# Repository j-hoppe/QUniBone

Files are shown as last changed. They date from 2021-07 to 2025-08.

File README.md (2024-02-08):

# QUniBone
This is the software for both
Linux-to-UNIBUS bridge "UniBone"
and
Linux-to-QBUS bridge "QBone"

"UniBone" connects a BeagleBone Black micro Linux system to ancient DEC UNIBUS,
"QBone" does the same for DEC QBUS.

UniBone/QBone can keep old PDP-11s running, by emulating devices and aiding in repair.

As UNIBUS and QBUS are quite similar, only one software project compiles for both devices.

In-source differentiation is done via "#define UNIBUS" or "#define QBUS".
Source files special to only one bus are marked with suffix "_u" respective "_q".

See project pages at retrocmp.com [for UniBone](http://retrocmp.com/projects/unibone/) and [for QBone](http://retrocmp.com/projects/qbone/)

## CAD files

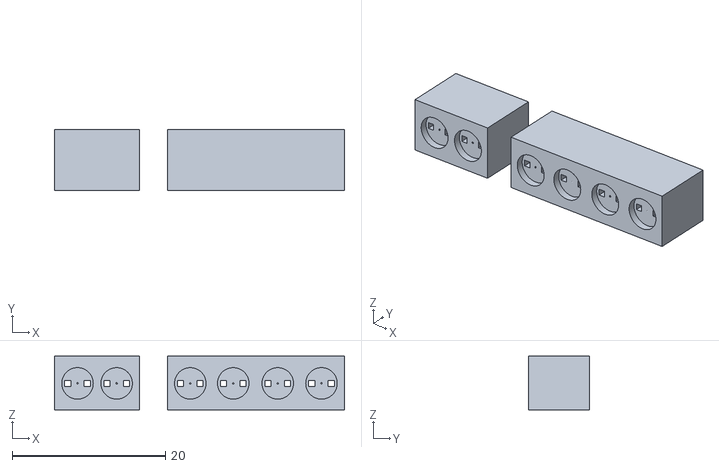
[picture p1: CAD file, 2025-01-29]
01.01_pcb/3d/UniBone2023Leds3mm.stl
37.8 x 8.00 x 7.00

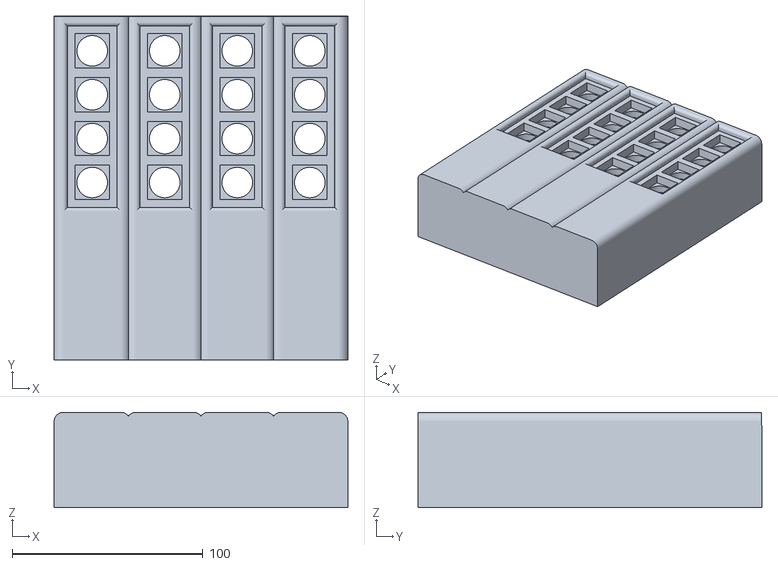
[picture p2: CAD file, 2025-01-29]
01.02_panel/building/rl02panel.stl
154.0 x 180.2 x 50.0

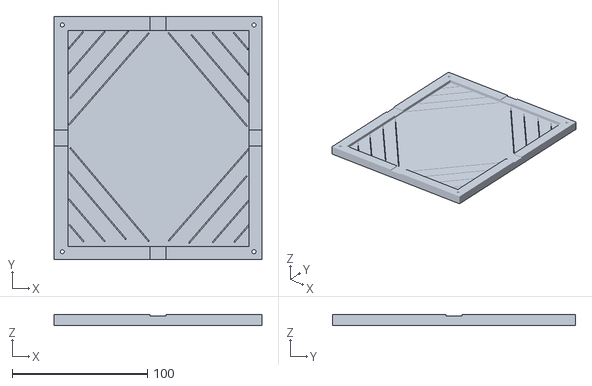
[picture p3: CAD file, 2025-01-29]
01.02_panel/building/rl02panel-bottom.stl
154.0 x 180.0 x 8.00

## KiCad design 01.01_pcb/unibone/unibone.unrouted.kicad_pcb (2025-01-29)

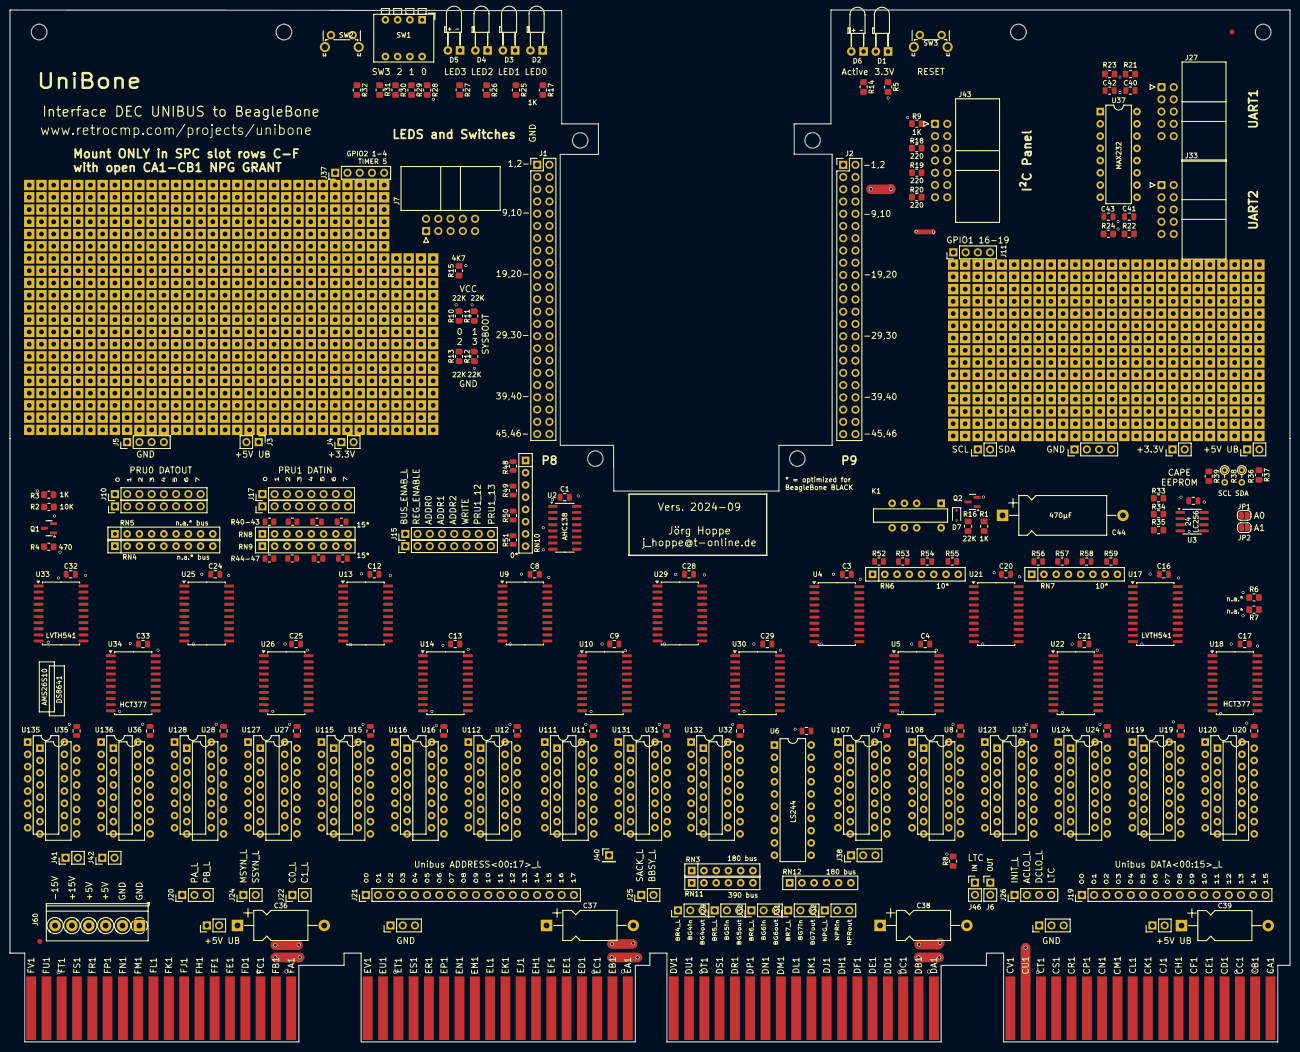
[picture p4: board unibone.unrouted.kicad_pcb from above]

Board: 4 copper layers, 265.6 x 214.1 mm, 1317 parts (0 on the bottom side), 321 nets.

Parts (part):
C1, C2, C3, C4, C5, C6, C7, C8, C9, C10, C11, C12, C13, C14, C15, C16, C17, C18, C19, C20, C21, C22, C23, C24, C25, C26, C27, C28, C29, C30, C31, C32, C33, C34, C35: 100nF; C_0805_2012Metric
C36, C37, C38, C39: 6.3uF; CP_Axial_L11.0mm_D6.0mm_P18.00mm_Horizontal
C40, C41, C42, C43: 1uF; C_0805_2012Metric
C44: 470uF; CP_Axial_L18.0mm_D8.0mm_P25.00mm_Horizontal
D1: PWR; LED_D3.0mm_Horizontal_O3.81mm_Z2.0mm
D2: LED0; LED_D3.0mm_Horizontal_O3.81mm_Z2.0mm
D3: LED1; LED_D3.0mm_Horizontal_O3.81mm_Z2.0mm
D4: LED2; LED_D3.0mm_Horizontal_O3.81mm_Z2.0mm
D5: LED3; LED_D3.0mm_Horizontal_O3.81mm_Z2.0mm
D6: ONBUS; LED_D3.0mm_Horizontal_O3.81mm_Z2.0mm
D7: 1N4148WS; D_SOD-323
DECHANDLE1, DECHANDLE2: DEC Handle; DEC-Handle
F1, F2: Fiducial
H1, H2, H7, H8: NPTH; HOLE-3MM
HOLE1, HOLE2, HOLE3, HOLE4: MountingHole_3.2mm_M3
J1: BBB-P8; PinHeader_2x23_P2.54mm_Vertical
J2: BBB-P9; PinHeader_2x23_P2.54mm_Vertical
J3, J35: +5V UB; PinHeader_1x02_P2.54mm_Vertical
J4, J34: +3.3V; PinHeader_1x02_P2.54mm_Vertical
J5, J36: GND; PinHeader_1x04_P2.54mm_Vertical
J6: LTC_OUT; PinHeader_1x02_P2.54mm_Vertical
J7: Panel; IDC-Header_2x05_P2.54mm_Horizontal
J10: REG_DATA_FROM_PRU0; PinHeader_1x08_P2.54mm_Vertical
J11: GPIO1_16-19; PinHeader_1x04_P2.54mm_Vertical
J13, J14: GND; PinHeader_1x03_P2.54mm_Vertical
J15: PRU_CONTROL; PinHeader_1x08_P2.54mm_Vertical
J16: CONN-DEC-QUAD-CDEF; dec-conn-quad-ht-pins-only_CDEF
J17: REG_DATA_TO_PRU1; PinHeader_1x08_P2.54mm_Vertical
J19: UB_DATA; PinHeader_1x16_P2.54mm_Vertical
J20: UB_INTR_PAB; PinHeader_1x03_P2.54mm_Vertical
J21: UB_ADDR; PinHeader_1x18_P2.54mm_Vertical
J22: UB_C01; PinHeader_1x02_P2.54mm_Vertical
J23, J56, J57: GND; PinHeader_1x08_P2.54mm_Vertical
J24: UB_MSYN; PinHeader_1x02_P2.54mm_Vertical
J25: UB_SKBY; PinHeader_1x02_P2.54mm_Vertical
J26: UB_MISC; PinHeader_1x04_P2.54mm_Vertical
J27: UART1_RS232_Schneid-Klemm_2x5; IDC-Header_2x05_P2.54mm_Horizontal
J28: UB_BRG4; PinHeader_1x03_P2.54mm_Vertical
J29: UB_BRG5; PinHeader_1x03_P2.54mm_Vertical
J30: UB_BRG6; PinHeader_1x03_P2.54mm_Vertical
J31: UB_BRG7; PinHeader_1x03_P2.54mm_Vertical
J32: UB_NPRG; PinHeader_1x03_P2.54mm_Vertical
J33: UART2_RS232_Schneid-Klemm_2x5; IDC-Header_2x05_P2.54mm_Horizontal
J37: GPIO2_1-5; PinHeader_1x05_P2.54mm_Vertical
J38: -; PinHeader_1x03_P2.54mm_Vertical
J40: Conn_01x01; PinHeader_1x01_P2.54mm_Vertical
J41, J42, J61, J62: Conn_01x02_Male; PinHeader_1x02_P2.54mm_Vertical
J43: Panel_I2C; IDC-Header_2x07_P2.54mm_Horizontal
J46: LTC_IN; PinHeader_1x02_P2.54mm_Vertical
J59: I2C2; PinHeader_1x02_P2.54mm_Vertical
J60: Reichelt AKL 059-6; TerminalBlock_Phoenix_PT-1,5-6-3.5-H_1x06_P3.50mm_Horizontal
JP1: A0; SolderJumper-2_P1.3mm_Open_RoundedPad1.0x1.5mm
JP2: A1; SolderJumper-2_P1.3mm_Open_RoundedPad1.0x1.5mm
K1: HFD3; HFD3-relay
Q1, Q2: MMBT3904; SOT-23
R1, R3, R8, R9, R17, R25, R26, R27, R28, R29, R30, R31, R32: 1K; R_0805_2012Metric_Pad1.20x1.40mm_HandSolder
R2, R33, R34, R35, R37, R39: 10K; R_0805_2012Metric_Pad1.20x1.40mm_HandSolder
R4, R5, R14: 470; R_0805_2012Metric_Pad1.20x1.40mm_HandSolder
R6, R7: none; R_0805_2012Metric_Pad1.20x1.40mm_HandSolder
R10, R11, R12, R13, R16: 22K; R_0805_2012Metric_Pad1.20x1.40mm_HandSolder
R15: 4K7; R_0805_2012Metric_Pad1.20x1.40mm_HandSolder
R18, R19, R20: 220; R_0805_2012Metric_Pad1.20x1.40mm_HandSolder
R21, R22: 2K2; R_0805_2012Metric_Pad1.20x1.40mm_HandSolder
R23, R24: 3K3; R_0805_2012Metric_Pad1.20x1.40mm_HandSolder
R36, R38: opt.; R_Axial_DIN0204_L3.6mm_D1.6mm_P2.54mm_Vertical
R40, R41, R42, R43, R44, R45, R46, R47: 15; R_0805_2012Metric
R48, R49, R50, R51: 0; R_0805_2012Metric
R52, R53, R54, R55, R56, R57, R58, R59: 10; R_0805_2012Metric
RN3, RN12: 180; R_Array_SIP6
RN4, RN5: n.a.; R_Array_SIP9
RN6, RN7: 10; R_Array_SIP8
RN8, RN9: 15; R_Array_SIP8
RN10: 0; R_Array_SIP8
RN11: 390; R_Array_SIP6
SW1: SW0-3; SW_DIP_SPSTx04_Piano_CTS_Series194-4MSTN_W7.62mm_P2.54mm
SW2, SW3: BTN; SW_Tactile_SPST_Angled_PTS645Vx58-2LFS
U2: 74AHC138; SOIC-16_3.9x9.9mm_P1.27mm
U3: 24LC256; SOIC-8_3.9x4.9mm_P1.27mm
U4, U9, U13, U17, U21, U25, U29, U33: 74LVTH541_PWR; SOIC-20W_7.5x12.8mm_P1.27mm
U5, U10, U14, U18, U22, U26, U30, U34: 74HCT377; SOIC-20W_7.5x12.8mm_P1.27mm
U6: 74LS244_5V; DIP-20_W7.62mm
U7, U8, U11, U12, U15, U16, U19, U20, U23, U24, U27, U28, U31, U32, U35, U36: DS8641-LR; DIP-16_W7.62mm
U37: MAX232; DIP-16_W7.62mm
U107, U108, U111, U112, U115, U116, U119, U120, U123, U124, U127, U128, U131, U132, U135, U136: AM26S10; DIP-16_W7.62mm
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

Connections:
+3.3V: C1.2, C2.1, C3.2, C8.2, C12.2, C16.2, C20.2, C24.2, C28.2, C32.2, D1.2 (A), D2.2 (A), D3.2 (A), D4.2 (A), D5.2 (A), D6.2 (A), J2.3, J2.4, J4.1, J4.2, J34.1, J34.2, J43.5, JP1.2 (B), JP2.2 (B), R6.1, R10.1, R11.1, R35.1, R36.1, R37.1, R38.1, R39.1, RN5.1 (common), SW1.1, SW1.2, SW1.3, SW1.4, SW2.1, U2.16 (VCC), U3.8 (VCC), U4.20 (VCC), U9.20 (VCC), U13.20 (VCC), U17.20 (VCC), U21.20 (VCC), U25.20 (VCC), U29.20 (VCC), U33.20 (VCC)
+5VA: J2.5, J2.6, K1.5, K1.8, U37.16 (VCC)
/DS8641-ADR07/busdriver3/in1: U10.2 (Q0), U11.14 (in1), U111.13 (4D)
/DS8641-ADR07/busdriver3/in2: U10.5 (Q1), U11.11 (in2), U111.11 (3D)
/DS8641-ADR07/busdriver3/in3: U10.6 (Q2), U11.2 (in3), U111.4 (1D)
/DS8641-ADR07/busdriver3/in4: U10.9 (Q3), U11.5 (in4), U111.5 (2D)
/DS8641-ADR07/busdriver3/out1: U9.2 (A0), U11.13 (out1), U111.14 (4R)
/DS8641-ADR07/busdriver3/out2: U9.3 (A1), U11.10 (out2), U111.10 (3R)
/DS8641-ADR07/busdriver3/out3: U9.4 (A2), U11.3 (out3), U111.3 (1R)
/DS8641-ADR07/busdriver3/out4: U9.5 (A3), U11.6 (out4), U111.6 (2R)
/DS8641-ADR07/busdriver4/in1: U10.12 (Q4), U12.14 (in1), U112.13 (4D)
/DS8641-ADR07/busdriver4/in2: U10.15 (Q5), U12.11 (in2), U112.11 (3D)
/DS8641-ADR07/busdriver4/in3: U10.16 (Q6), U12.2 (in3), U112.4 (1D)
/DS8641-ADR07/busdriver4/in4: U10.19 (Q7), U12.5 (in4), U112.5 (2D)
/DS8641-ADR07/busdriver4/out1: U9.6 (A4), U12.13 (out1), U112.14 (4R)
/DS8641-ADR07/busdriver4/out2: U9.7 (A5), U12.10 (out2), U112.10 (3R)
/DS8641-ADR07/busdriver4/out3: U9.8 (A6), U12.3 (out3), U112.3 (1R)
/DS8641-ADR07/busdriver4/out4: U9.9 (A7), U12.6 (out4), U112.6 (2R)
/DS8641-ADR167+MSYN/busdriver3/in1: U26.2 (Q0), U27.14 (in1), U127.13 (4D)
/DS8641-ADR167+MSYN/busdriver3/in2: U26.5 (Q1), U27.11 (in2), U127.11 (3D)
/DS8641-ADR167+MSYN/busdriver3/in3: U26.6 (Q2), U27.2 (in3), U127.4 (1D)
/DS8641-ADR167+MSYN/busdriver3/in4: U26.9 (Q3), U27.5 (in4), U127.5 (2D)
/DS8641-ADR167+MSYN/busdriver3/out1: U25.2 (A0), U27.13 (out1), U127.14 (4R)
/DS8641-ADR167+MSYN/busdriver3/out2: U25.3 (A1), U27.10 (out2), U127.10 (3R)
/DS8641-ADR167+MSYN/busdriver3/out3: U25.4 (A2), U27.3 (out3), U127.3 (1R)
/DS8641-ADR167+MSYN/busdriver3/out4: U25.5 (A3), U27.6 (out4), U127.6 (2R)
/DS8641-ADR167+MSYN/busdriver4/bus3: J41.1, U28.1 (bus3), U128.2 (1B)
/DS8641-ADR167+MSYN/busdriver4/bus4: J41.2, U28.4 (bus4), U128.7 (2B)
/DS8641-ADR167+MSYN/busdriver4/in1: U26.12 (Q4), U28.14 (in1), U128.13 (4D)
/DS8641-ADR167+MSYN/busdriver4/in2: U26.15 (Q5), U28.11 (in2), U128.11 (3D)
/DS8641-ADR167+MSYN/busdriver4/in3: U26.16 (Q6), U28.2 (in3), U128.4 (1D)
/DS8641-ADR167+MSYN/busdriver4/in4: U26.19 (Q7), U28.5 (in4), U128.5 (2D)
/DS8641-ADR167+MSYN/busdriver4/out1: U25.6 (A4), U28.13 (out1), U128.14 (4R)
/DS8641-ADR167+MSYN/busdriver4/out2: U25.7 (A5), U28.10 (out2), U128.10 (3R)
/DS8641-ADR167+MSYN/busdriver4/out3: U25.8 (A6), U28.3 (out3), U128.3 (1R)
/DS8641-ADR167+MSYN/busdriver4/out4: U25.9 (A7), U28.6 (out4), U128.6 (2R)
/DS8641-ADR815/busdriver3/in1: U14.2 (Q0), U15.14 (in1), U115.13 (4D)
/DS8641-ADR815/busdriver3/in2: U14.5 (Q1), U15.11 (in2), U115.11 (3D)
/DS8641-ADR815/busdriver3/in3: U14.6 (Q2), U15.2 (in3), U115.4 (1D)
/DS8641-ADR815/busdriver3/in4: U14.9 (Q3), U15.5 (in4), U115.5 (2D)
/DS8641-ADR815/busdriver3/out1: U13.2 (A0), U15.13 (out1), U115.14 (4R)
/DS8641-ADR815/busdriver3/out2: U13.3 (A1), U15.10 (out2), U115.10 (3R)
/DS8641-ADR815/busdriver3/out3: U13.4 (A2), U15.3 (out3), U115.3 (1R)
/DS8641-ADR815/busdriver3/out4: U13.5 (A3), U15.6 (out4), U115.6 (2R)
/DS8641-ADR815/busdriver4/in1: U14.12 (Q4), U16.14 (in1), U116.13 (4D)
/DS8641-ADR815/busdriver4/in2: U14.15 (Q5), U16.11 (in2), U116.11 (3D)
/DS8641-ADR815/busdriver4/in3: U14.16 (Q6), U16.2 (in3), U116.4 (1D)
/DS8641-ADR815/busdriver4/in4: U14.19 (Q7), U16.5 (in4), U116.5 (2D)
/DS8641-ADR815/busdriver4/out1: U13.6 (A4), U16.13 (out1), U116.14 (4R)
/DS8641-ADR815/busdriver4/out2: U13.7 (A5), U16.10 (out2), U116.10 (3R)
/DS8641-ADR815/busdriver4/out3: U13.8 (A6), U16.3 (out3), U116.3 (1R)
/DS8641-ADR815/busdriver4/out4: U13.9 (A7), U16.6 (out4), U116.6 (2R)
/DS8641-ARB/busdriver3/in1: U30.2 (Q0), U31.14 (in1), U131.13 (4D)
/DS8641-ARB/busdriver3/in2: U30.5 (Q1), U31.11 (in2), U131.11 (3D)
/DS8641-ARB/busdriver3/in3: U30.6 (Q2), U31.2 (in3), U131.4 (1D)
/DS8641-ARB/busdriver3/in4: U30.9 (Q3), U31.5 (in4), U131.5 (2D)
/DS8641-ARB/busdriver3/out1: U29.2 (A0), U31.13 (out1), U131.14 (4R)
/DS8641-ARB/busdriver3/out2: U29.3 (A1), U31.10 (out2), U131.10 (3R)
/DS8641-ARB/busdriver3/out3: U29.4 (A2), U31.3 (out3), U131.3 (1R)
/DS8641-ARB/busdriver3/out4: U29.5 (A3), U31.6 (out4), U131.6 (2R)
/DS8641-ARB/busdriver4/bus4: J40.1, U32.4 (bus4), U132.7 (2B)
/DS8641-ARB/busdriver4/in1: U30.12 (Q4), U32.14 (in1), U132.13 (4D)
/DS8641-ARB/busdriver4/in2: U30.15 (Q5), U32.11 (in2), U132.11 (3D)
/DS8641-ARB/busdriver4/in3: U30.16 (Q6), U32.2 (in3), U132.4 (1D)
/DS8641-ARB/busdriver4/in4: U30.19 (Q7), U32.5 (in4), U132.5 (2D)
/DS8641-ARB/busdriver4/out1: U29.6 (A4), U32.13 (out1), U132.14 (4R)
/DS8641-ARB/busdriver4/out2: U29.7 (A5), U32.10 (out2), U132.10 (3R)
/DS8641-ARB/busdriver4/out3: U29.8 (A6), U32.3 (out3), U132.3 (1R)
/DS8641-ARB/busdriver4/out4: U29.9 (A7), U32.6 (out4), U132.6 (2R)
/DS8641-DAT07/busdriver3/in1: U18.2 (Q0), U19.14 (in1), U119.13 (4D)
/DS8641-DAT07/busdriver3/in2: U18.5 (Q1), U19.11 (in2), U119.11 (3D)
/DS8641-DAT07/busdriver3/in3: U18.6 (Q2), U19.2 (in3), U119.4 (1D)
/DS8641-DAT07/busdriver3/in4: U18.9 (Q3), U19.5 (in4), U119.5 (2D)
/DS8641-DAT07/busdriver3/out1: U17.2 (A0), U19.13 (out1), U119.14 (4R)
/DS8641-DAT07/busdriver3/out2: U17.3 (A1), U19.10 (out2), U119.10 (3R)
/DS8641-DAT07/busdriver3/out3: U17.4 (A2), U19.3 (out3), U119.3 (1R)
/DS8641-DAT07/busdriver3/out4: U17.5 (A3), U19.6 (out4), U119.6 (2R)
/DS8641-DAT07/busdriver4/in1: U18.12 (Q4), U20.14 (in1), U120.13 (4D)
/DS8641-DAT07/busdriver4/in2: U18.15 (Q5), U20.11 (in2), U120.11 (3D)
/DS8641-DAT07/busdriver4/in3: U18.16 (Q6), U20.2 (in3), U120.4 (1D)
/DS8641-DAT07/busdriver4/in4: U18.19 (Q7), U20.5 (in4), U120.5 (2D)
/DS8641-DAT07/busdriver4/out1: U17.6 (A4), U20.13 (out1), U120.14 (4R)
/DS8641-DAT07/busdriver4/out2: U17.7 (A5), U20.10 (out2), U120.10 (3R)
/DS8641-DAT07/busdriver4/out3: U17.8 (A6), U20.3 (out3), U120.3 (1R)
/DS8641-DAT07/busdriver4/out4: U17.9 (A7), U20.6 (out4), U120.6 (2R)
/DS8641-DAT815/busdriver3/in1: U22.2 (Q0), U23.14 (in1), U123.13 (4D)
/DS8641-DAT815/busdriver3/in2: U22.5 (Q1), U23.11 (in2), U123.11 (3D)
/DS8641-DAT815/busdriver3/in3: U22.6 (Q2), U23.2 (in3), U123.4 (1D)
/DS8641-DAT815/busdriver3/in4: U22.9 (Q3), U23.5 (in4), U123.5 (2D)
/DS8641-DAT815/busdriver3/out1: U21.2 (A0), U23.13 (out1), U123.14 (4R)
/DS8641-DAT815/busdriver3/out2: U21.3 (A1), U23.10 (out2), U123.10 (3R)
/DS8641-DAT815/busdriver3/out3: U21.4 (A2), U23.3 (out3), U123.3 (1R)
/DS8641-DAT815/busdriver3/out4: U21.5 (A3), U23.6 (out4), U123.6 (2R)
/DS8641-DAT815/busdriver4/in1: U22.12 (Q4), U24.14 (in1), U124.13 (4D)
/DS8641-DAT815/busdriver4/in2: U22.15 (Q5), U24.11 (in2), U124.11 (3D)
/DS8641-DAT815/busdriver4/in3: U22.16 (Q6), U24.2 (in3), U124.4 (1D)
/DS8641-DAT815/busdriver4/in4: U22.19 (Q7), U24.5 (in4), U124.5 (2D)
/DS8641-DAT815/busdriver4/out1: U21.6 (A4), U24.13 (out1), U124.14 (4R)
/DS8641-DAT815/busdriver4/out2: U21.7 (A5), U24.10 (out2), U124.10 (3R)
/DS8641-DAT815/busdriver4/out3: U21.8 (A6), U24.3 (out3), U124.3 (1R)
/DS8641-DAT815/busdriver4/out4: U21.9 (A7), U24.6 (out4), U124.6 (2R)
/DS8641-SSYN+MISC/busdriver3/in1: U34.2 (Q0), U35.14 (in1), U135.13 (4D)
/DS8641-SSYN+MISC/busdriver3/in2: U34.5 (Q1), U35.11 (in2), U135.11 (3D)
/DS8641-SSYN+MISC/busdriver3/in3: U34.6 (Q2), U35.2 (in3), U135.4 (1D)
/DS8641-SSYN+MISC/busdriver3/in4: U34.9 (Q3), U35.5 (in4), U135.5 (2D)
/DS8641-SSYN+MISC/busdriver3/out1: U33.2 (A0), U35.13 (out1), U135.14 (4R)
/DS8641-SSYN+MISC/busdriver3/out2: U33.3 (A1), U35.10 (out2), U135.10 (3R)
/DS8641-SSYN+MISC/busdriver3/out3: U33.4 (A2), U35.3 (out3), U135.3 (1R)
/DS8641-SSYN+MISC/busdriver3/out4: U33.5 (A3), U35.6 (out4), U135.6 (2R)
/DS8641-SSYN+MISC/busdriver4/bus3: J42.1, U36.1 (bus3), U136.2 (1B)
/DS8641-SSYN+MISC/busdriver4/bus4: J42.2, U36.4 (bus4), U136.7 (2B)
/DS8641-SSYN+MISC/busdriver4/in1: U34.12 (Q4), U36.14 (in1), U136.13 (4D)
/DS8641-SSYN+MISC/busdriver4/in2: U34.15 (Q5), U36.11 (in2), U136.11 (3D)
/DS8641-SSYN+MISC/busdriver4/in3: U34.16 (Q6), U36.2 (in3), U136.4 (1D)
/DS8641-SSYN+MISC/busdriver4/in4: U34.19 (Q7), U36.5 (in4), U136.5 (2D)
/DS8641-SSYN+MISC/busdriver4/out1: U33.6 (A4), U36.13 (out1), U136.14 (4R)
/DS8641-SSYN+MISC/busdriver4/out2: U33.7 (A5), U36.10 (out2), U136.10 (3R)
/DS8641-SSYN+MISC/busdriver4/out3: U33.8 (A6), U36.3 (out3), U136.3 (1R)
/DS8641-SSYN+MISC/busdriver4/out4: U33.9 (A7), U36.6 (out4), U136.6 (2R)
/SELECT0_L: U2.15 (O0), U4.19 (G2), U5.1 (EO)
/SELECT1_L: U2.14 (O1), U29.19 (G2), U30.1 (EO)
/SELECT2_L: U2.13 (O2), U9.19 (G2), U10.1 (EO)
/SELECT3_L: U2.12 (O3), U13.19 (G2), U14.1 (EO)
/SELECT4_L: U2.11 (O4), U25.19 (G2), U26.1 (EO)
/SELECT5_L: U2.10 (O5), U17.19 (G2), U18.1 (EO)
/SELECT6_L: U2.9 (O6), U21.19 (G2), U22.1 (EO)
/SELECT7_L: U2.7 (O7), U33.19 (G2), U34.1 (EO)
/TTL_IN_OUT/BUS_IN_DAT6: J38.1, U6.15 (I2b)
/TTL_IN_OUT/BUS_IN_DAT7: J38.2, U6.17 (I3b)
/TTL_IN_OUT/busdriver1/in1: U5.2 (Q0), U8.14 (in1), U108.13 (4D)
/TTL_IN_OUT/busdriver1/in2: U5.5 (Q1), U8.11 (in2), U108.11 (3D)
/TTL_IN_OUT/busdriver1/in3: U5.6 (Q2), U8.2 (in3), U108.4 (1D)
/TTL_IN_OUT/busdriver1/in4: U5.9 (Q3), U8.5 (in4), U108.5 (2D)
/TTL_IN_OUT/busdriver1/out1: U8.13 (out1), U108.14 (4R)
/TTL_IN_OUT/busdriver1/out2: U8.10 (out2), U108.10 (3R)
/TTL_IN_OUT/busdriver1/out3: U8.3 (out3), U108.3 (1R)
/TTL_IN_OUT/busdriver1/out4: U8.6 (out4), U108.6 (2R)
/TTL_IN_OUT/busdriver2/bus3: J38.3, U7.1 (bus3), U107.2 (1B)
/TTL_IN_OUT/busdriver2/in1: U5.12 (Q4), U7.14 (in1), U107.13 (4D)
/TTL_IN_OUT/busdriver2/in2: U5.15 (Q5), U7.11 (in2), U107.11 (3D)
/TTL_IN_OUT/busdriver2/in3: U5.16 (Q6), U7.2 (in3), U107.4 (1D)
/TTL_IN_OUT/busdriver2/out1: U7.13 (out1), U107.14 (4R)
/TTL_IN_OUT/busdriver2/out2: U7.10 (out2), U107.10 (3R)
/TTL_IN_OUT/busdriver2/out3: U7.3 (out3), U107.3 (1R)
/TTL_IN_OUT/busdriver2/out4: U7.6 (out4), U107.6 (2R)
/misc-io/EEPROM_A0: JP1.1 (A), R33.1, U3.1 (A0)
/misc-io/EEPROM_A1: JP2.1 (A), R34.1, U3.2 (A1)
BG4_IN_H: J16.DS2, J28.2, RN3.2 (R1), RN11.2 (R1), U6.2 (I0a)
BG4_OUT_H: J16.DT2, J28.3, RN12.2 (R1), U8.15 (bus1), U108.15 (4B)
BG5_IN_H: J16.DP2, J29.2, RN3.3 (R2), RN11.3 (R2), U6.4 (I1a)
BG5_OUT_H: J16.DR2, J29.3, RN12.3 (R2), U8.12 (bus2), U108.9 (3B)
BG6_IN_H: J16.DM2, J30.2, RN3.4 (R3), RN11.4 (R3), U6.6 (I2a)
BG6_OUT_H: J16.DN2, J30.3, RN12.4 (R3), U8.1 (bus3), U108.2 (1B)
BG7_IN_H: J16.DK2, J31.2, RN3.5 (R4), RN11.5 (R4), U6.8 (I3a)
BG7_OUT_H: J16.DL2, J31.3, RN12.5 (R4), U8.4 (bus4), U108.7 (2B)
BUS_ENABLE: J1.11, R2.2, R3.2
BUS_ENABLE_L: J15.1, Q1.3 (C), R4.2, U7.9 (disA), U8.9 (disA), U11.9 (disA), U12.9 (disA), U15.9 (disA), U16.9 (disA), U19.9 (disA), U20.9 (disA), U23.9 (disA), U24.9 (disA), U27.9 (disA), U28.9 (disA), U31.9 (disA), U32.9 (disA), U35.9 (disA), U36.9 (disA), U107.12 (S), U108.12 (S), U111.12 (S), U112.12 (S), U115.12 (S), U116.12 (S), U119.12 (S), U120.12 (S), U123.12 (S), U124.12 (S), U127.12 (S), U128.12 (S), U131.12 (S), U132.12 (S), U135.12 (S), U136.12 (S)
BUTTON: J1.12, J7.10, R32.1, SW2.2
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

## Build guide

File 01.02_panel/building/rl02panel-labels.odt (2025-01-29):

LOAD | 0 READY | FAULT | WRITE PROT

LOAD | 1 READY | FAULT | WRITE PROT

LOAD | 2 READY | FAULT | WRITE PROT

LOAD | 3 READY | FAULT | WRITE PROT

RLO2 RLO2 RLO2

LOAD | 0 READY | FAULT | WRITE PROT

LOAD | 1 READY | FAULT | WRITE PROT

LOAD | 2 READY | FAULT | WRITE PROT

LOAD | 3 READY | FAULT | WRITE PROT

LOAD | 0 READY | FAULT | WRITE PROT

LOAD | 1 READY | FAULT | WRITE PROT

LOAD | 2 READY | FAULT | WRITE PROT

LOAD | 3 READY | FAULT | WRITE PROT

RLO2 RLO2 RLO2

LOAD | 0 READY | FAULT | WRITE PROT

LOAD | 1 READY | FAULT | WRITE PROT

LOAD | 2 READY | FAULT | WRITE PROT

LOAD | 3 READY | FAULT | WRITE PROT

LOAD | 0 READY | FAULT | WRITE PROT

LOAD | 1 READY | FAULT | WRITE PROT

LOAD | 2 READY | FAULT | WRITE PROT

LOAD | 3 READY | FAULT | WRITE PROT

RLO2 RLO2 RLO2

LOAD | 0 READY | FAULT | WRITE PROT

LOAD | 1 READY | FAULT | WRITE PROT

LOAD | 2 READY | FAULT | WRITE PROT

LOAD | 3 READY | FAULT | WRITE PROT

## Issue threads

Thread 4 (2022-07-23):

Ordered shutdown of BBB

2lostkiwis, 2022-07-23:
I'm not sure if this is the right location for a discussion, apologies if it's not.
In the FAQ it mentions it's not been a problem just cutting power to the BBB without a safe shutdown.
That is probably true, but would it be possible to trigger a safe shutdown by monitoring the pushbutton switch that's wired to an IO (not the RESET one) to do a safe shutdown?
I don't normally have a console connected to the BBB so this would be a nice way to trigger it before turning off the power if the switch is not used for anything else.

j-hoppe, 2022-07-23:
Hi,
> I'm not sure if this is the right location for a discussion, apologies if it's not.

The correct location is

https://groups.google.com/g/unibone

You may need to register ... not a big thing.

I'll answer your question there, it may be of ttnerest to others.

kind regards,

Joerg

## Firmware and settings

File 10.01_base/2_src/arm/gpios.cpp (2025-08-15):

/* gpios_q.cpp: QBone functions for ARM and PRU GPIOs

 Copyright (c) 2018-2020, Joerg Hoppe
 j_hoppe@t-online.de, www.retrocmp.com

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

 21-may-2019  JH      added UNIBUS signals
 12-nov-2018  JH      entered beta phase
 */

#define _GPIOS_CPP_

#include <stdlib.h>
#include <stdint.h>
#include <string.h>
#include <time.h>
#include <assert.h>
#include <fcntl.h>
#include <sys/mman.h>
#include <sys/stat.h>

#include "mailbox.h"

#include "pru.hpp"
#include "utils.hpp"
#include "logsource.hpp"
#include "logger.hpp"
#include "timeout.hpp"

#include "gpios.hpp"

// see spruh73n.pdf
// address range of GPIO related registers. [spruh73n] page 181
#define GPIO_SIZE 	0x1000 // size of each GPIO register range
#define GPIO0_START_ADDR 0x44E07000
#define GPIO1_START_ADDR 0x4804C000
#define GPIO2_START_ADDR 0x481AC000
#define GPIO3_START_ADDR 0x481AE000 // offset in each GPIO register range
#define GPIO_OE_ADDROFFSET 0x134
#define GPIO_DATAIN_ADDROFFSET 0x138
#define GPIO_DATAOUT_ADDROFFSET 0x13c
#define GPIO_SETDATAOUT_ADDROFFSET 0x194
#define GPIO_CLEARDATAOUT_ADDROFFSET 0x190

gpios_c *gpios; // Singleton

gpios_c::gpios_c() {
    log_label = "GPIOS";

    cmdline_leds = 0 ; // is set before init()
    leds_for_debug = false ;

    memory_filedescriptor = open((char*) "/dev/mem", O_RDWR);
    if (!memory_filedescriptor)
        FATAL("Can not open /dev/mem");

}

/* fill the 4 gpio_banks with values and
 *	map addresses
 */
void gpios_c::bank_map_registers(unsigned bank_idx, unsigned unmapped_start_addr)
{
    gpio_bank_t *bank;

    assert(bank_idx < 4);

    bank = &(banks[bank_idx]);
    bank->gpios_in_use = 0;
    bank->registerrange_addr_unmapped = unmapped_start_addr; // info only
    INFO("GPIO%d registers at %X - %X (size = %X)", bank_idx, unmapped_start_addr,
         unmapped_start_addr + GPIO_SIZE - 1, GPIO_SIZE);
    bank->registerrange_start_addr = (uint8_t *) mmap(0, GPIO_SIZE, PROT_READ | PROT_WRITE,
                                     MAP_SHARED, memory_filedescriptor, unmapped_start_addr);
    if (bank->registerrange_start_addr == MAP_FAILED)
        FATAL("Unable to map GPIO%d", bank_idx);

    bank->oe_addr = (uint32_t *) (bank->registerrange_start_addr + GPIO_OE_ADDROFFSET);
    bank->datain_addr = (uint32_t *) (bank->registerrange_start_addr + GPIO_DATAIN_ADDROFFSET);
    bank->dataout_addr =
        (uint32_t *) (bank->registerrange_start_addr + GPIO_DATAOUT_ADDROFFSET);
    bank->setdataout_addr = (uint32_t *) (bank->registerrange_start_addr
                                          + GPIO_SETDATAOUT_ADDROFFSET);
    bank->clrdataout_addr = (uint32_t *) (bank->registerrange_start_addr
                                          + GPIO_CLEARDATAOUT_ADDROFFSET);
}

gpio_config_t *gpios_c::config(const char *name, int direction, unsigned bank_idx,
                               unsigned pin_in_bank)
{
    gpio_config_t *result = (gpio_config_t *) malloc(sizeof(gpio_config_t));
    if (name)
        strcpy(result->name, name);
    else
        strcpy(result->name, "");
    if (strlen(result->name) > 0)
        result->internal = 0;
    else
        result->internal = 1;
    result->direction = direction;
    assert(bank_idx < 4);
    result->bank_idx = bank_idx;
    result->bank = &(banks[bank_idx]);
    result->bank->gpios_in_use++;
    result->pin_in_bank = pin_in_bank;
    result->linear_no = 32 * bank_idx + pin_in_bank;
    result->pin_in_bank_mask = 1 << pin_in_bank;

    return result;
}

// "export" a pin over the sys file system
// this is necessary for GPIO2&3, despite we operate memory mapped.
void gpios_c::export_pin(gpio_config_t *pin)
{
    char fname[256];
    FILE *f;
    struct stat statbuff;

    sprintf(fname, "/sys/class/gpio/export");
    f = fopen(fname, "w");
    if (!f)
        FATAL("Can not open %s", fname);
    fprintf(f, "%d\n", pin->linear_no);
    fclose(f);

    // verify: now there should appear the control directory for the pin
    sprintf(fname, "/sys/class/gpio/gpio%d", pin->linear_no);
    if (stat(fname, &statbuff) != 0 || !S_ISDIR(statbuff.st_mode))
        FATAL("Gpio control dir %s not generated", fname);

}
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

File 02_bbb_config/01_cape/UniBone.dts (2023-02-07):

/* UniBone - Device Tree Overlay for enabling GPIOs, PRU GPIOs and UARTs
*
* This overlay is based on the BB-PRU-01 overlay
* Written by Derek Molloy for the book "Exploring BeagleBone: Tools and
* Techniques for Building with Embedded Linux" by John Wiley & Sons, 2014
* ISBN 9781118935125. Please see the file README.md in the repository root
* directory for copyright and GNU GPLv3 license information.
*/
/dts-v1/;
/plugin/;

/ {
   compatible = "ti,beaglebone", "ti,beaglebone-black";

   part-number = "UniBone";
   version = "00A0";

   /* This overlay uses the following resources */
   exclusive-use =
   // SW[0..3] input on regular GPIO
         "P8.23", "P8.22", "P8.3", "P8.4",
         // BUTTON input on regular GPIO
         "P8.12",

         // LED[0..3] output on regular GPIO
         "P8.25", "P8.24", "P8.5", "P8.6",

         // Driver & Register output enable output on regular GPIO
         "P8.11", "P8.16",

         // PRU0 REG_DATOUT[0..7] outputs
         // "P9.31", "P9.29", "P9.30", "P9.28", "P9.42", "P9.27", "P9.41", "P9.25",
	 // P9.41 & P9.42 not "exclisive" here, used by PRU
         "P9.31", "P9.29", "P9.30", "P9.28", "P9.27", "P9.25",

         // PRU1 REG_DATIN[0..7] inputs
         "P8.45", "P8.46", "P8.43", "P8.44", "P8.41", "P8.42", "P8.39", "P8.40",

         // PRU1 REG_ADR[0..2], REG_WRITE outputs
         "P8.27", "P8.29", "P8.28", "P8.30",
         // PRU1 Debugging output r30 pin 12  // ,13
         "P8.21",  // "P8.20",


         // Assert constant level on eMMC CMD input
         "P8.20",

         "P9.26", // Pin UART1 RXD
         "P9.24", // Pin UART1 TXD
         "P9.22", // Pin UART2 RXD
         "P9.21", // Pin UART2 TXD

         "P9.11",  // GPIO0_30: QBone activity LED
         "P9.12",  // GPIO1_28: I2C panel reset

         "P8.9",    // GPIO2_5: Timer5 output

         // ip used
         "pru0", "pru1",
         "uart1", "uart2"  // UARTs necessary here?
            ;

   fragment@0 {
      target = <&am33xx_pinmux>;
      __overlay__ {

        // <pinctrl memory register as offset from 0x44e10800> <value> pairs
        // value composed as sum of (SPRU73N, 9.2.2.2.0)
        // SLEWCTRL: 0 = fast, 0x40 = slow.
        // RXACTIVE: Input buffer enable. 0 = disable, 0x20 = enable
        // PULLTYPESEL: Pad pullup/pulldown. 0 = pull down, 0x10 = pull up
        // PULLUDEN: Pad pullup/down enable. 0 = enable, 0x08 = disable
        // MUXMODE: 0..7
         gpio_pins: pinmux_gpio_pins {         // The GPIO pins
            pinctrl-single,pins = <

               0x010  0x2f // SW0 input on P8.23: gpio1_4, rx, no pull up/dn, mode=7
               0x014  0x2f // SW1 input on P8.22: gpio1_5, rx, no pull up/dn, mode=7
               0x018  0x2f // SW2 input on P8.3: gpio1_6, rx, no pull up/dn, mode=7
               0x01c  0x2f // SW3 input on P8.4: gpio1_7, rx, no pull up/dn, mode=7
               0x030  0x2f // BUTTON input on P8.12: gpio1_12, rx, no pull up/dn, mode=7

               0x000  0x07 // LED0 output on P8.25: gpio1_0, pulldown, mode=7
               0x004  0x07 // LED1 output on P8.24: gpio1_1, pulldown, mode=7
               0x008  0x07 // LED2 output on P8.05: gpio1_2, pulldown, mode=7
               0x00c  0x07 // LED3 output on P8.06: gpio1_3, pulldown, mode=7
               0x038  0x17 // REG_ENABLE output on P8.16: gpio1_14, pullup, mode=7
               0x034  0x17 // BUS_ENABLE output on P8.11: gpio1_13, pullup, mode=7

               0x084 0x07 // Force constant level on eMMC CMD pin. P8.20 output gpio1_31, pulldown, mode=7

                // UARTs
               0x180 0x30 // UART1 RXD on P9.26, receiver, pullup, mode=0=UART1
               0x184 0x10 // UART1 TXD on P9.24, xmitter, pullup, mode=0=UART1
               0x150 0x31 // UART2 RXD on P9.22, receiver, pullup, mode=1=UART2
               0x154 0x11 // UART2 TXD on P9.21, xmitter, pullup, mode=1=UART2

                // Activity LED
               0x070 0x07 // LED output on P9.11: gpio0_30, pulldown, mode=7
                // I2C panel reset
               0x078 0x17 // I2C panel reset on P9.12: gpio1_28, pullup, mode=7

                // 50/60Hz generation on timer 5
               0x09c  0x02 // Timer5 output on P8.09, pulldown, mode=2

            >;
         };

         pru_pru_pins: pinmux_pru_pru_pins {   // The PRU pin modes
            pinctrl-single,pins = <
                 0x190 0x15 // PRU0 REG_DATOUT_0 on P9.31: pr1_pru0_pru_r30_0, fast, pullup, mode=5
                 0x194 0x15 // PRU0 REG_DATOUT_1 on P9.29: pr1_pru0_pru_r30_1, fast, pullup, mode=5
                 0x198 0x15 // PRU0 REG_DATOUT_2 on P9.30: pr1_pru0_pru_r30_2, fast, pullup, mode=5
                 0x19c 0x15 // PRU0 REG_DATOUT_3 on P9.28: pr1_pru0_pru_r30_3, fast, pullup, mode=5
                 0x1a0 0x15 // PRU0 REG_DATOUT_4 on P9.42: pr1_pru0_pru_r30_4, fast, pullup, mode=5
                 0x1a4 0x15 // PRU0 REG_DATOUT_5 on P9.27: pr1_pru0_pru_r30_5, fast, pullup, mode=5
                 0x1a8 0x15 // PRU0 REG_DATOUT_6 on P9.41: pr1_pru0_pru_r30_6, fast, pullup, mode=5
                 0x1ac 0x15 // PRU0 REG_DATOUT_7 on P9.25: pr1_pru0_pru_r30_7, fast, pullup, mode=5
                 0x164 0x2f // P9.42 REG_DATOUT_4 tied to GPIO0_7: GPIO tristate! input, no pull up/dn, mode=7
                 0x1b4 0x2f // P9.41 REG_DATOUT_6 tied to GPIO0_20: GPIO tristate! input, no pull up/dn, mode=7

                 0x0a0 0x2e // PRU1 REG_DATIN_0 on P8.45: pr1_pru1_pru_r31_0, fast, rx, no pulldown, mode6
                 0x0a4 0x2e // PRU1 REG_DATIN_1 on P8.46: pr1_pru1_pru_r31_1, fast, rx, no pulldown, mode6
                 0x0a8 0x2e // PRU1 REG_DATIN_2 on P8.43: pr1_pru1_pru_r31_2, fast, rx, no pulldown, mode6
                 0x0ac 0x2e // PRU1 REG_DATIN_3 on P8.44: pr1_pru1_pru_r31_3, fast, rx, no pulldown, mode6
                 0x0b0 0x2e // PRU1 REG_DATIN_4 on P8.41: pr1_pru1_pru_r31_4, fast, rx, no pulldown, mode6
                 0x0b4 0x2e // PRU1 REG_DATIN_5 on P8.42: pr1_pru1_pru_r31_5, fast, rx, no pulldown, mode6
                 0x0b8 0x2e // PRU1 REG_DATIN_6 on P8.39: pr1_pru1_pru_r31_6, fast, rx, no pulldown, mode6
                 0x0bc 0x2e // PRU1 REG_DATIN_7 on P8.40: pr1_pru1_pru_r31_7, fast, rx, no pulldown, mode6
                 // 0x0bc 0x36 // PRU1 REG_DATIN_7 on P8.40: pr1_pru1_pru_r31_7, fast, rx, pullup, mode6
                 // 0x0bc 0x26 // PRU1 REG_DATIN_7 on P8.40: pr1_pru1_pru_r31_7, fast, rx, pulldown, mode6
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

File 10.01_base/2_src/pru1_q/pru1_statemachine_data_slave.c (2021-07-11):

/* pru1_statemachine_data_slave.c: state machine for execution of slave DATO* or DATI* cycles

Copyright (c) 2018-2020, Joerg Hoppe
j_hoppe@t-online.de, www.retrocmp.com

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

27-aug-2020    JH      QBUS variant
29-jun-2019    JH      rework: state returns ptr to next state func
12-nov-2018    JH  entered beta phase

Statemachine for execution of slave DATO* or DATI* cycles.

*/
#include <stdlib.h>
#include <stdint.h>
#include <stdbool.h>
#include "pru1_utils.h"
#include "mailbox.h"
#include "ddrmem.h"
#include "iopageregister.h"
#include "pru1_buslatches.h"
#include "pru1_statemachine_data_slave.h"
// static variables
statemachine_data_slave_t sm_data_slave;

// returns next state
// big switch(), 5ns per case
enum states_data_slave_enum  sm_data_slave_func(enum states_data_slave_enum  /**/ state) {
    while(1) {
        // normally process states in high speed loop.
        // some long states return so main() can process other SMs
        // MUST return to main() if !EVENT_IS_ACKED, so PRU checks for AMR2PPRU opcodes on devcie register access!
        switch(state) {
        case state_data_slave_stop:
        case state_data_slave_start:
        {
            uint8_t latch0val, latch1val, latch2val ;
            uint32_t addr;
            latch2val = buslatches_getbyte(2);
            //	  latch3val = buslatches_getbyte(3); // SYNC latched signals
            if (! (latch2val & BIT(7))) {
#ifdef TUNING_ODT_HALT_DETECTION
            sm_data_slave.console_cycle_active = false ;
#endif
                return state_data_slave_stop; // no SYNC, or refresh cycle
            }
            // SYNC: DAL is latched
            latch0val = buslatches_getbyte(0);
            latch1val = buslatches_getbyte(1);

            // decode addresses from DAL and BS7, always 22+1bit
            // encode BS7 as high addr bit #22. on 16 and 18 bit systems, pullup must set unused ADDRs to 1 = negated
            addr = latch0val | ((uint32_t) latch1val << 8) | ((uint32_t) (latch2val & 0x7f) << 16);
            sm_data_slave.addr = addr; // save

            //	  if (!(latch2val & BIT(6))) // pulse when not BS7
            //		  PRU_DEBUG_PIN0(1);
            
#ifdef TUNING_ODT_HALT_DETECTION
            if ( !sm_data_slave.console_cycle_active) {
                // Check only once per SYNC, else counter running.
                // valid cycle started: recognize ODT HALT: Microcode is then accessing the UART for user interaction
                // Trigger on repeated DIN/DOUT access to UART without other QBUS cycles in between.
                // In normal code execution always program fetches to other addresses are seen.
                // ! May also trigger on *cached* code loops !
                uint32_t	uart_mask = QUNIBUS_IOPAGE_ADDR_BITMASK | 0017770 ; // iopage local address with bit0:2 don't care
                uint32_t	uart_addr = QUNIBUS_IOPAGE_ADDR_BITMASK | 0177560 ; // UART base addr + BS7
                if ((addr & uart_mask) == (uart_addr & uart_mask) ) {
                    // din/dout to uart.
                    sm_data_slave.console_cycle_active = true ;
					switch(sm_data_slave.console_continuous_accesses) {
					// console_continuous_accesses counts 0, 1	(signal!), 2, 2 ...
					case 0: 
						sm_data_slave.console_continuous_accesses++ ;
						break ;
    				case 1: 
                        // only one pulse on transition! then reset by PRU activity again
                        PRU_DEBUG_PIN0(1) ; // signal to LA
						sm_data_slave.console_continuous_accesses++ ;
						break ;
					default: ; // 2 forever
                    }
                } else
                    sm_data_slave.console_continuous_accesses = 0 ;
            }
#endif


            // DO NOT EVALUATED WTBT for early DIN/DOUT decision ... perhaps later optimization
            state = state_data_slave_dindout_start; //
            break ;
        }
        case state_data_slave_dindout_start:
            // wait for DIN, then return prefetched memory value,
            // or start ioregister event to ARM
        {
            uint8_t latch4val;

            latch4val = buslatches_getbyte(4);
            if (((latch4val & BIT(0)) == 0) || (latch4val & BIT(3)) != 0 || (latch4val & BIT(7)) != 0) {
                // ! SYNC || RPLY || INIT
                // KD11F M8186 holds SYNC asserted in DCOK-INIT -> deadlock on PRU-power cycle
                return state_data_slave_stop; // master aborted, or other device accepted (missing SYNC cycle?)
            }


            if (latch4val & BIT(1)) { // DIN?

                // fast return of present value, then long delay
                // until ARM is ready when event acked
                uint16_t val;
                uint8_t emulated_addr_res = emulated_addr_read(sm_data_slave.addr, &val) ;

                if (!emulated_addr_res) { // read val from iopage register
                    return state_data_slave_stop; // non existing address
                }
                //		  PRU_DEBUG_PIN0(1);

                buslatches_setbyte(0, val & 0xff);					// DAL7..0
                buslatches_setbyte(1, (val >> 8) & 0xff);			// DAL15..8
                // DAL21 must be negated to indicate "no parity".
                // Implicitely true, as master removes address from DAL after SYNC, and we don't set DAL21 with other vlaues

                // "setbyte(2,0) only once, see above
                buslatches_setbits(4, BIT(3)+BIT(6), 0xff); 			 // REF=1: more DIN allowed, RPLY

                // RPLY asserted while ARM processes iopage register event, else timeout
                // from now on, "Abort" must clear REF: 		buslatches_setbits(4, BIT(6), 0) ; // clear REF: allow Block mode
                if (emulated_addr_res == 1)
                    state = state_data_slave_din_single_complete ; // mem access: no need to wait for ARM EVENT_ACK
                else
                    return state_data_slave_din_single_complete; // main(): check for ARM EVENT_ACK
            } else if (latch4val & BIT(2)) {  // DOUT ?
                uint32_t addr = sm_data_slave.addr;
                uint8_t emulated_addr_res ;
                // access to DAL in latches[0,1,2] transparent
                buslatches_setbyte(3, BIT(0)) ; // unlatch DAL to see data
                if (latch4val & BIT(4)) { // WTBT? byte access!
                    uint8_t b;
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

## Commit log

2020-09-29 DMA BS7 handling
2020-09-29 "demo"-scripts feedback start via LEDs
2020-09-29 Autostart application on power-on, later ssh session may connect to it ("screen" untility)
2020-09-30 Replaced hundreds of "UNIBUS" strings with "QBUS/UNIBUS"
    [buslatches.cpp, gpios.cpp]
2020-10-02 Aribtration: DMA ZKMA parallel to QUniBOne mem test OK
2020-10-13 Fix. On UniBone UNIBUS DMA addresses got IOpage bit 22 QUNIBUS_IOPAGE_ADDR_BITMASK set, this was meant only for the QBone PRU.
2021-01-21 Added 22-bit DMA flag to UDA sync handshake, as well as options to configure the controller to support it, and to identify as either a UDA50 or an RQDX3 controller.
    Minor code cleanup.
2021-01-21 UDA "22bit DMA" flag defaults to QBUS address width
2021-01-22 fixed 11/53 lock. INIT not delayed by DMR, event processed before device register access
2021-01-25 QBone 2021-02 Activity-LED
2021-02-07 CPU20 switch register not updated for running CPU
2021-02-16 PRU device register event signaling changed
2021-02-18 printf of image unzip actions
2021-03-10 Refactoring: storageimage (file control) separated from storagedrive (basic device functions)
2021-03-12 LED0 is disc activity
2021-03-13 LEDs have a "debug" mode
2021-03-20 4 drive activity leds
2021-07-11 - fix memory emulation upper boundary to odd address (eg. 157777 instead of 157776) LSI11/03 M7264 failed ZKMA because of DATI to 157777 - Optional ODT-HALT trigger on PRU_DEBUG_PIN0
    [pru1_statemachine_data_slave.c]
2022-01-16 RX11 and RX211 in separate priority slots
2022-07-24 I2C test menu - worker() control
2023-02-07 Timer5 output enabled
2023-02-07 GPIO, Timer5 output enabled with 50 Hz
2023-02-07 gpio loopback test: qunibus activity led inverted
    [gpios.cpp]
2023-02-15 Initial checkin for KE11-A emulation. Not currently passing diagnostics.
2023-02-25 Fix for RF11 default slot assignment (no longer conflicts with RK11)
2023-03-01 XCSR xmt emoty not set aufter enable ... reset() called on power event
2025-01-29 added Unibone KiCad project
    [DS8641.kicad_sch, TTL_IN_OUT.kicad_sch, busdriver.kicad_sch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]
2025-01-29 added RL02 case
    [UniBone2023Leds3mm.stl, rl02panel-bottom.stl, rl02panel.stl]
2025-04-29 Enable 2nd serial UART as DL11
2025-07-29 new device "blinkenbone"
2025-08-15 blinkenbone device final
2025-08-15 Fixing all Windows CRLF to Linux LF with "dos2unix -k *"
    [gpios.cpp]
